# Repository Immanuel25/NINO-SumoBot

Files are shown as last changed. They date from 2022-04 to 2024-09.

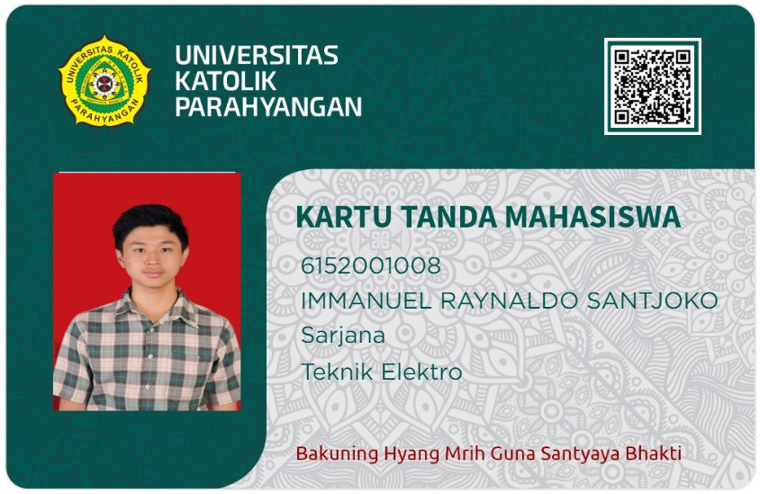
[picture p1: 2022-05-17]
NINO/ADM/KTM_Immanuel Raynaldo.jpg

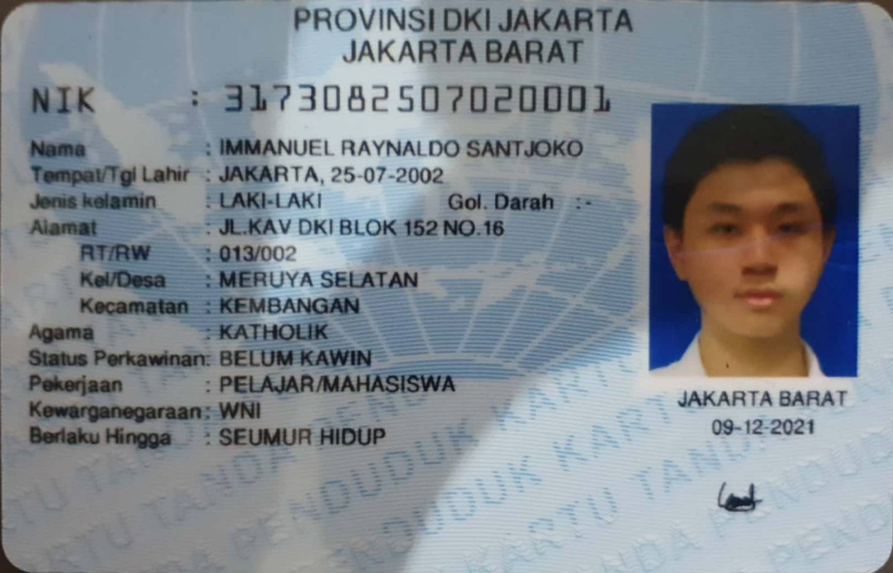
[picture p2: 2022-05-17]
NINO/ADM/KTP_Immanuel Raynaldo.jpg

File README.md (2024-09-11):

# Sumorobot Project

This repository contains the hardware and software files for a sumorobot built using an ESP32 and controlled via a PS4 controller. The robot weighs 2.5 kg and is designed for sumo robot competitions.

## Features

- **ESP32 and PS4 Controller**: The sumorobot is controlled wirelessly using the PS4 controller, offering real-time control with responsive movements.
- **2.5kg Weight**: Optimized for sumo robot competitions with a robust build and weight.
- **Custom Hardware and Software**: Includes both the hardware design and software code necessary to operate the robot.

## How to Use

1. Clone the repository.
2. Download and install PS4 to ESP32 library, check your PS4 bluetooth mac adress and update the code.
3. Upload the code to your ESP32 using Arduino IDE or PlatformIO.
4. Connect the PS4 controller wirelessly via Bluetooth.
5. Assemble the hardware components as per the documentation.

## Contributing

Feel free to fork this repository and submit pull requests with improvements or additional features.

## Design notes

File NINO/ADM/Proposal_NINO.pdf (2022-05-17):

# NINO

Niko & Noel

## LAMPIRAN

Daftar Komponen & Jadwal Kegiatan (https://docs.google.com/spreadsheets/d/1sjoTqLaU7VVk1JxIgI_WoqWyt1DAkXqaIjDHaI9r2Wg/edit?usp=sharing) GitHub (https://github.com/Immanuel25/NINO-SumoBot)

# DESAIN MEKANIK

## DESAIN NINO

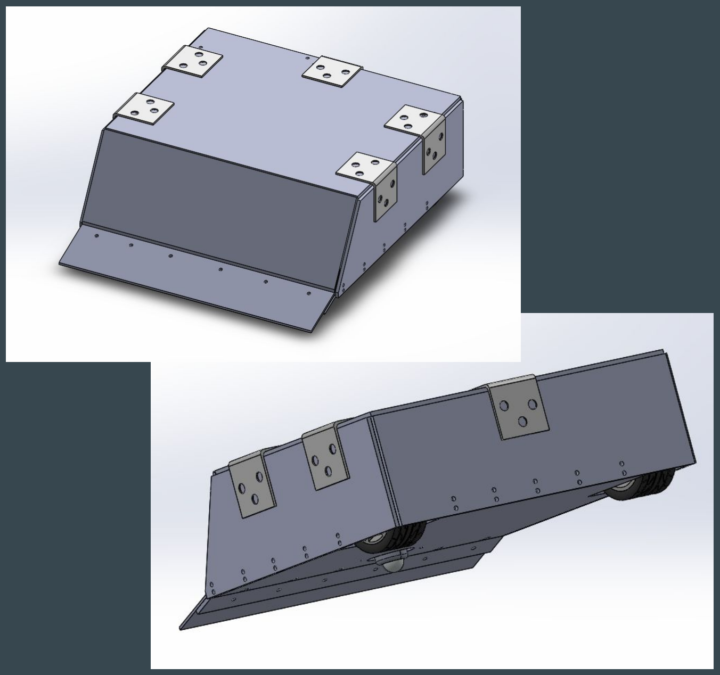
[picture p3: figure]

Bahan yang digunakan, Ketebalan :
1. Aluminium, 3mm : Untuk Plat Bawah
2. StainLess , 2mm : Untuk Ramp Bawah dan Ramp Atas
3. Akrilik, 3 mm : Untuk Penutup Atas, Kanan, Kiri , dan Belakang
Ukuran Sumo Robot :
Lebar = 24 +- cm
Panjang = 26 +- cm
Tinggi = 8,43 +- cm
Tinggi Plat Bawah ke tanah = 1 cm

## DESAIN NINO

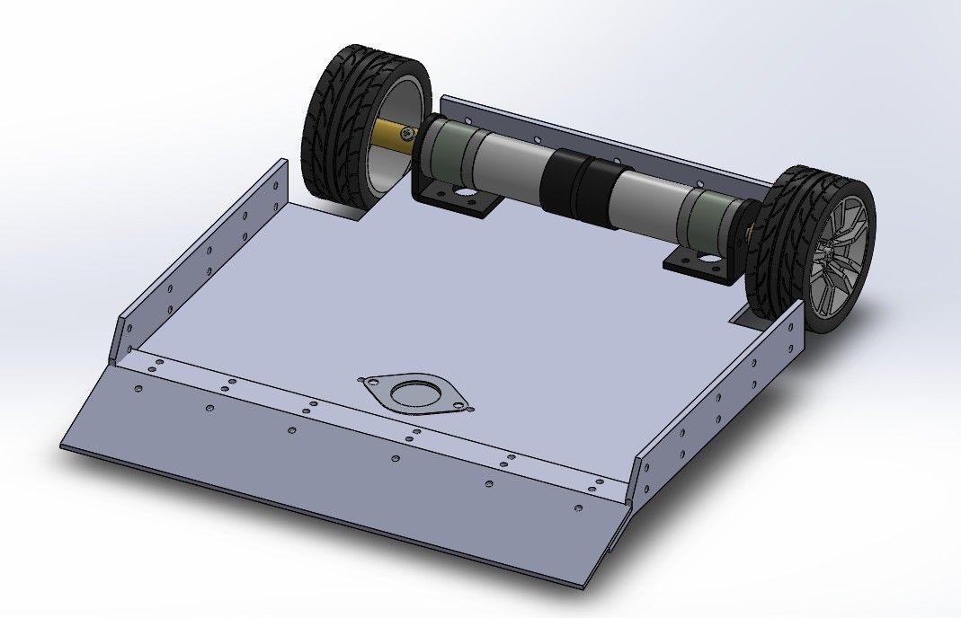
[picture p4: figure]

Bila Diberi Roda Akan tampak seperti ini

2 roda besar di belakang dan 1 caster di depan

Roda akan dicetak dengan bahan silikon menggunakan pipa paralon

Tampak Atas | Tampak Samping

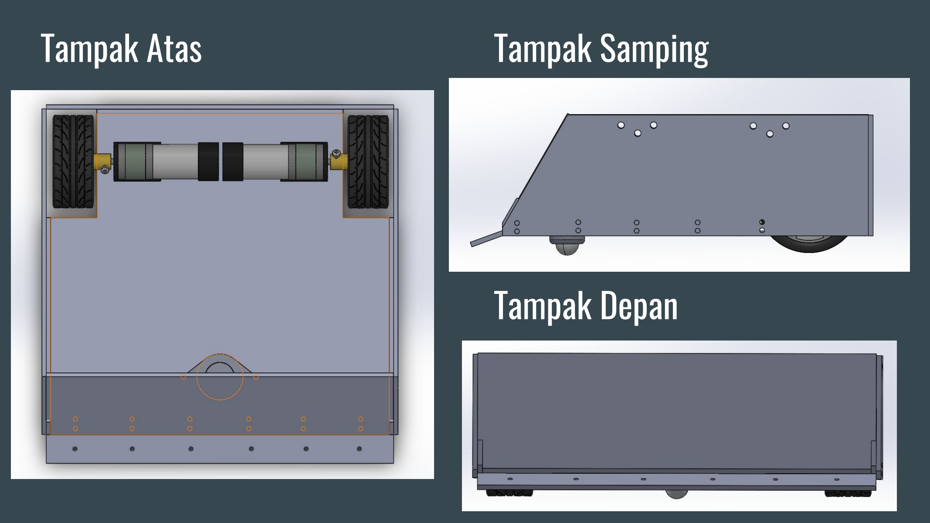
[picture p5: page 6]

## Tampak Depan

## DIMENSI DARI

ROBOT NINO | 15

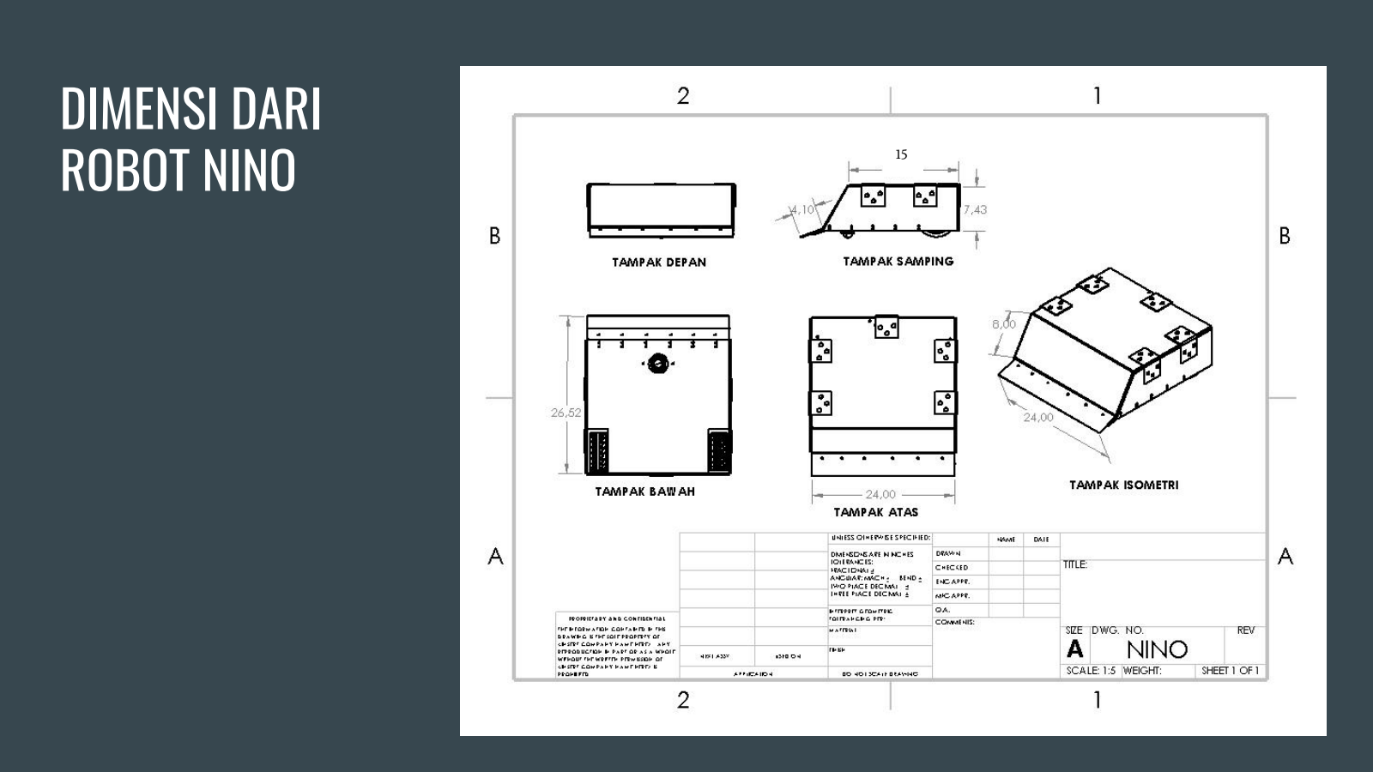
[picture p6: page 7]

## KOMPONEN MEKANIK

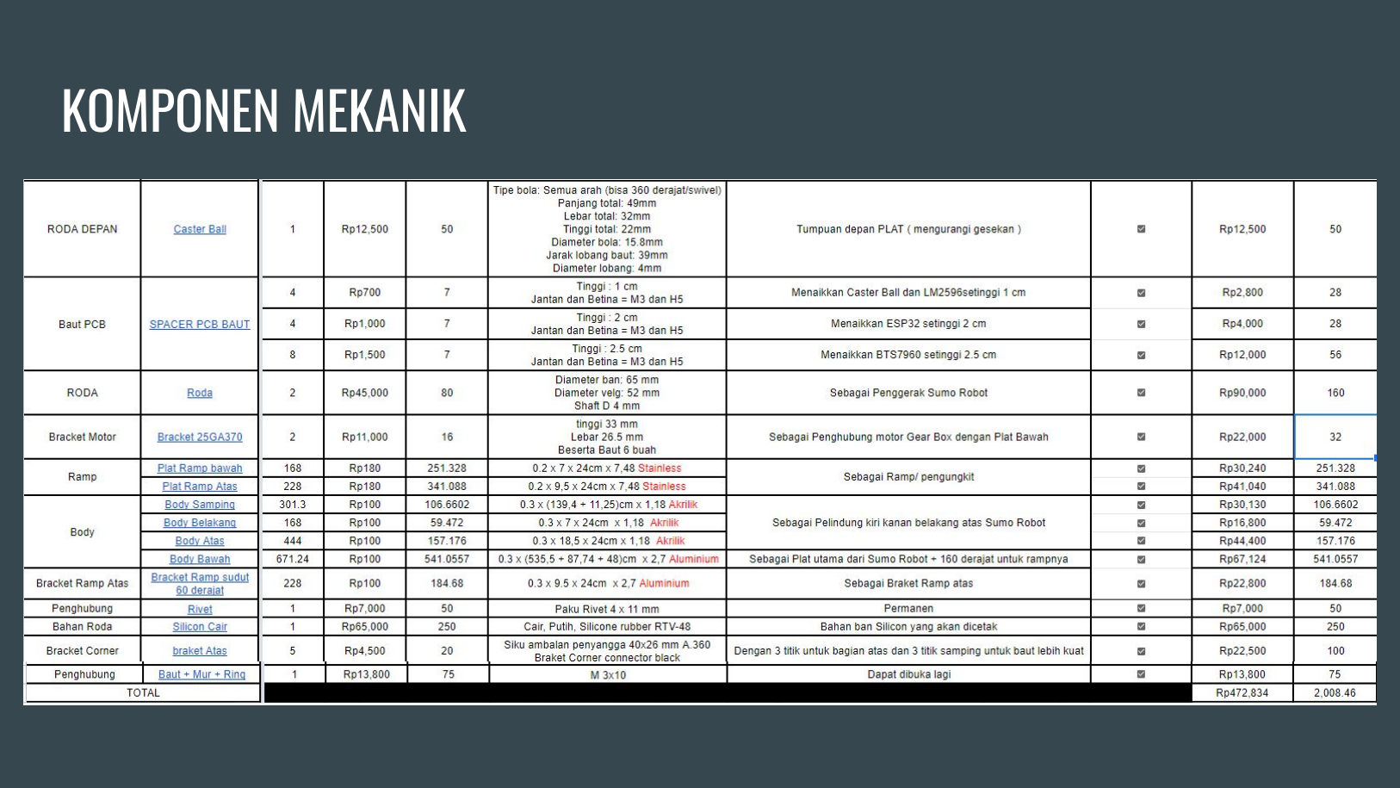
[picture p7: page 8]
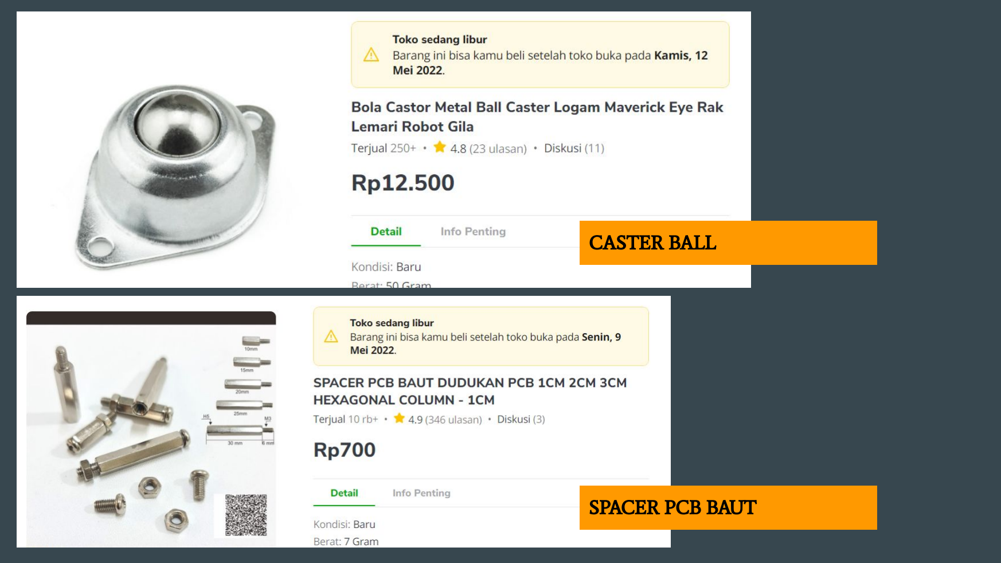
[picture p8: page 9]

CASTER BALL

SPACER PCB BAUT

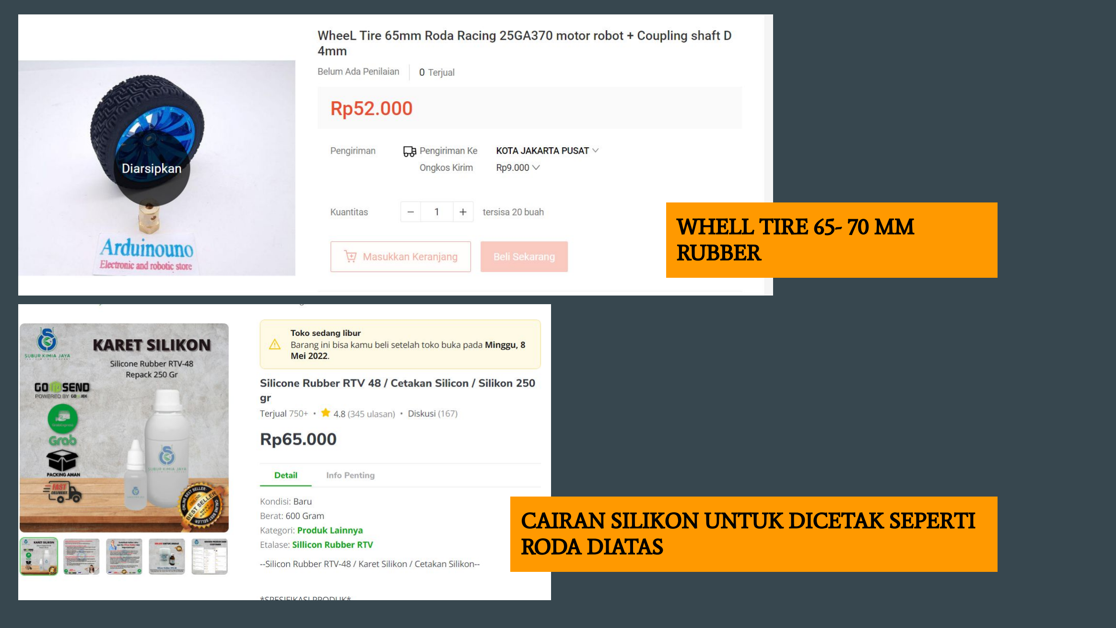
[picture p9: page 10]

WHELL TIRE 65- 70 MM
RUBBER

CAIRAN SILIKON UNTUK DICETAK SEPERTI RODA DIATAS

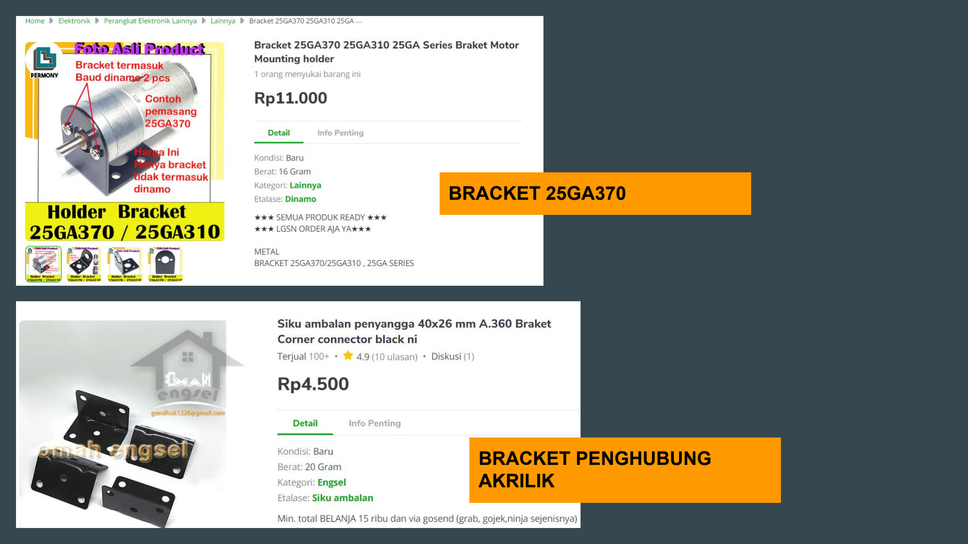
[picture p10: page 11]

BRACKET 25GA370

BRACKET PENGHUBUNG
AKRILIK

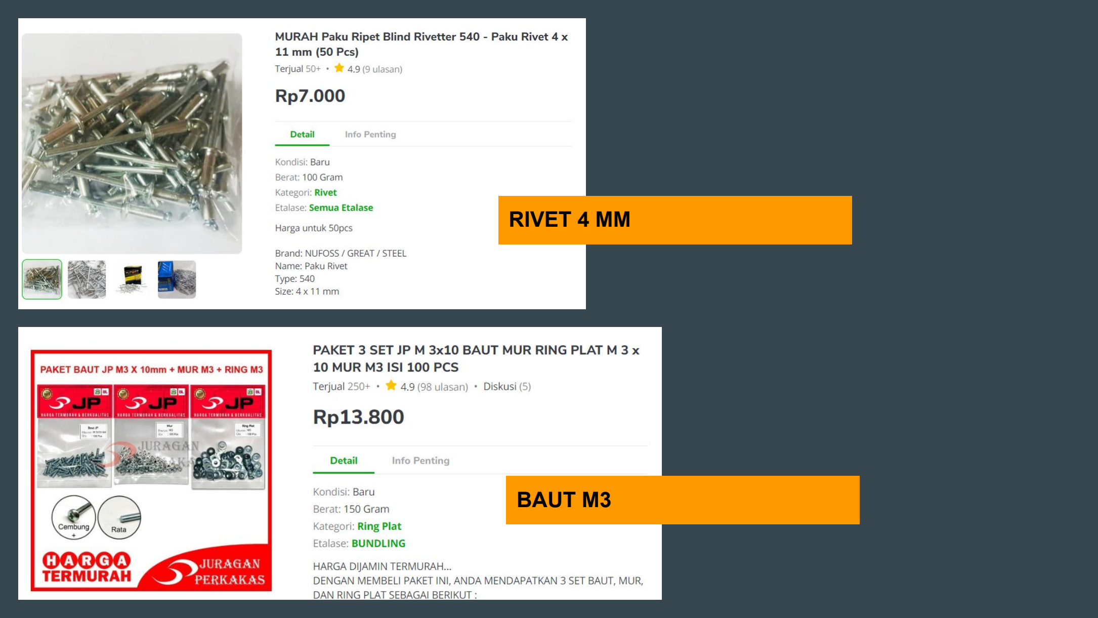
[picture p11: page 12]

RIVET 4 MM

BAUT M3

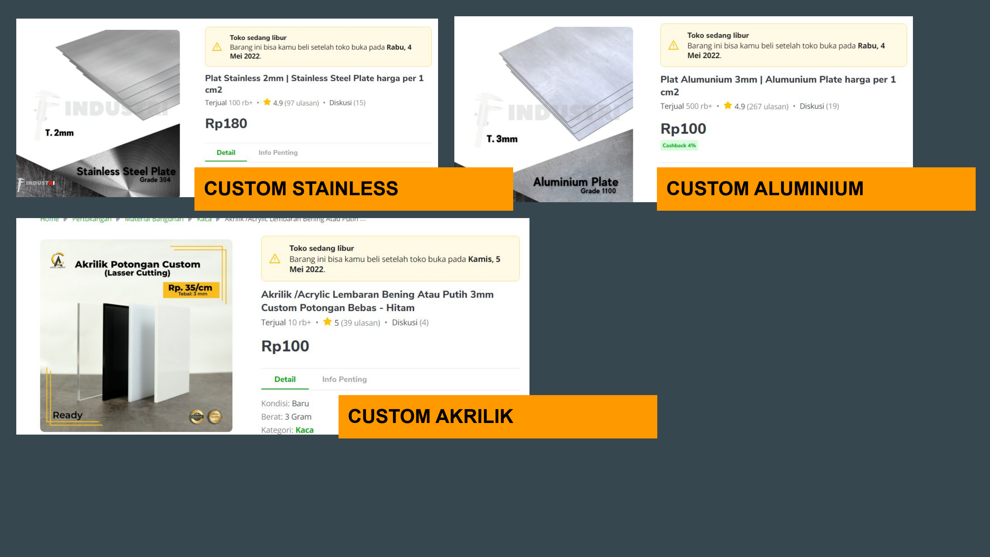
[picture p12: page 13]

CUSTOM AKRILIK

CUSTOM STAINLESS | CUSTOM ALUMINIUM

# KOMPONEN ELEKTRONIK

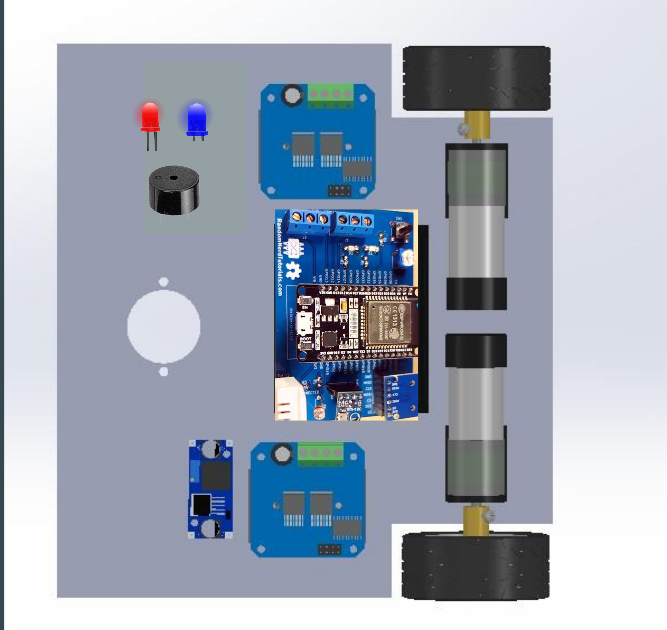
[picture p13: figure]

## RANGKAIAN ELEKTRONIK

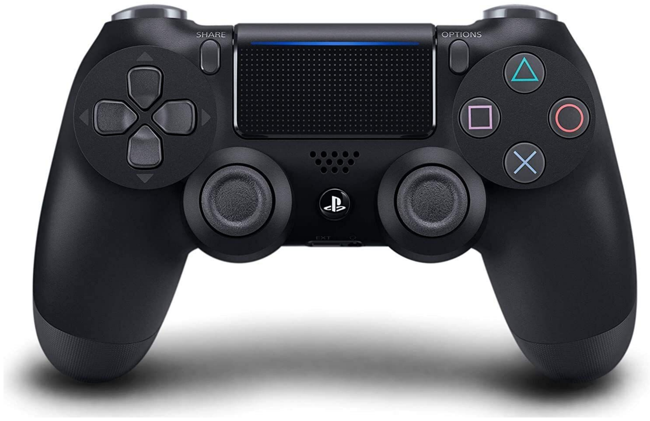
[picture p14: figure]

# KONTROLER

Sudah ada dan sudah terbiasa (karena sering main ps),
menggunakan bluetooth (ada librarynya)

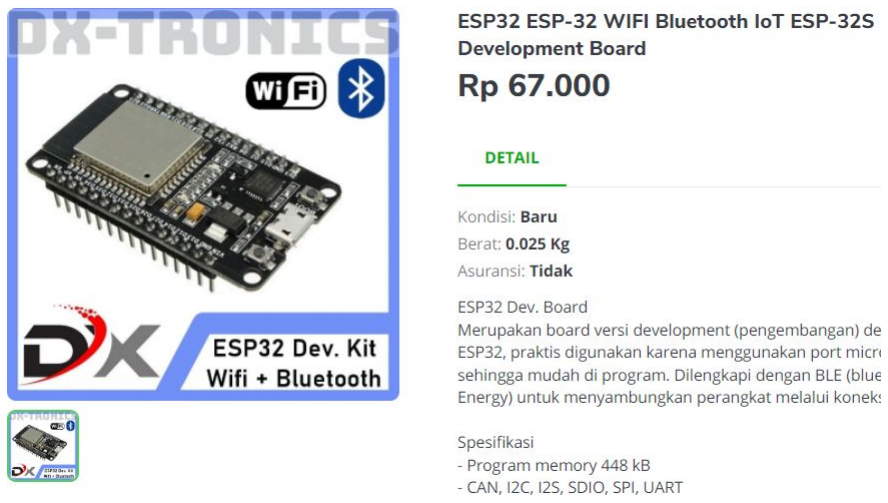
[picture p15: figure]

# MICRO CONTROLLER

Clock speednya lebih cepat 7.5x lipat dari arduino nano
integrated BLE V4.2

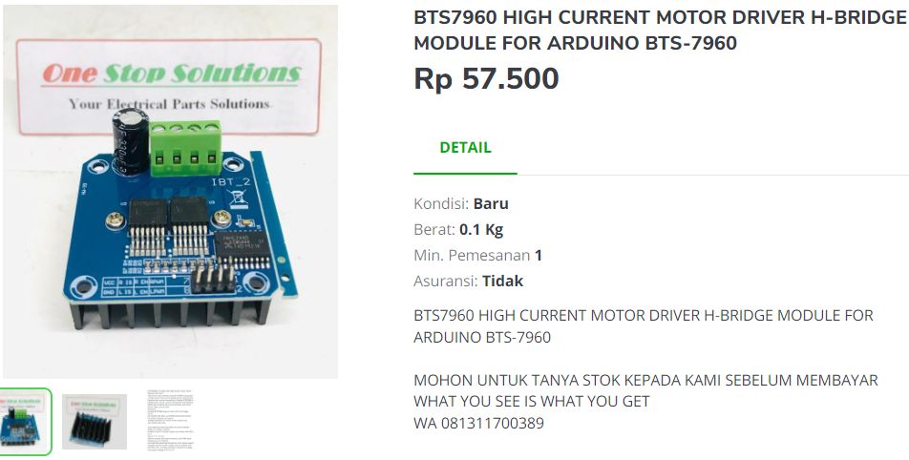
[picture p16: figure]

# MOTOR DRIVER

Menggunakan mosfet, arus max 43A, sudah ada heatsink, murah, ada pengukur arus (integrated)

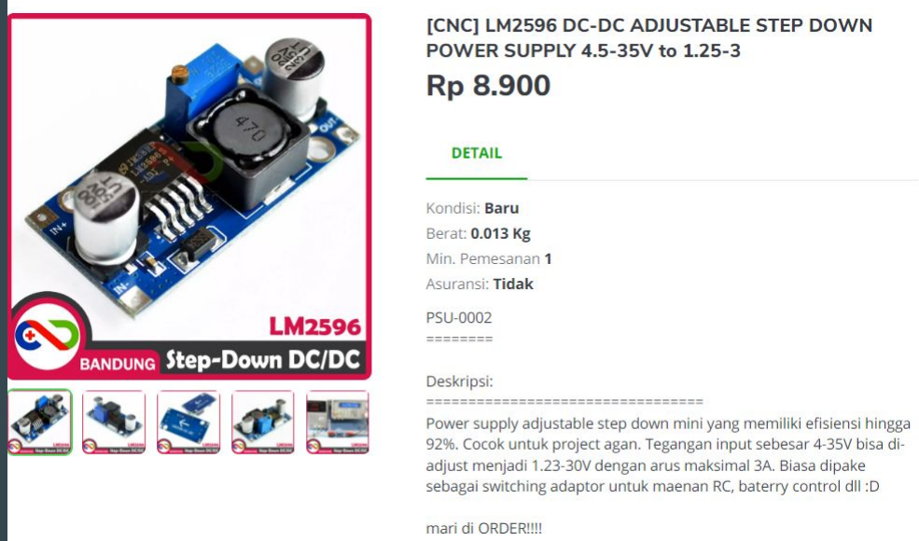
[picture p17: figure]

# STEP DOWN

## (PSU ESP32)

Bisa nurunin ke 6v, efisien, ringan

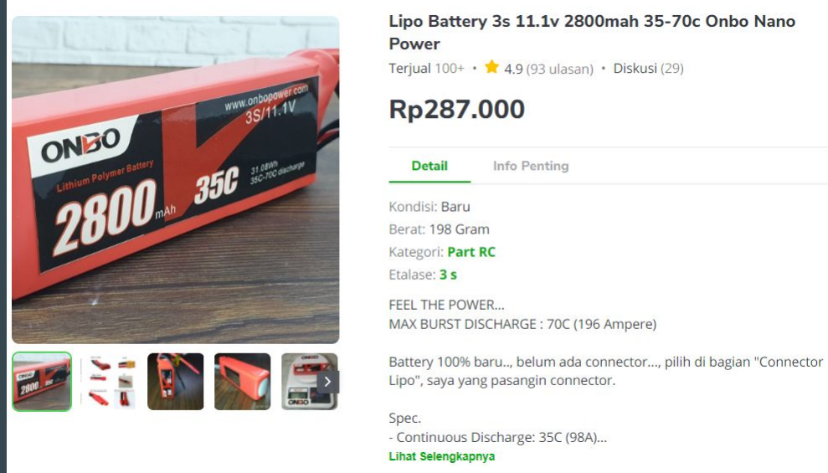
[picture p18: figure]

# Baterai

3S, artinya maks 12.6V, 2800 mah, Dalam pemakaian arus motor rata” (1A), robot dapat bertahan selama 1 jam 24 menit

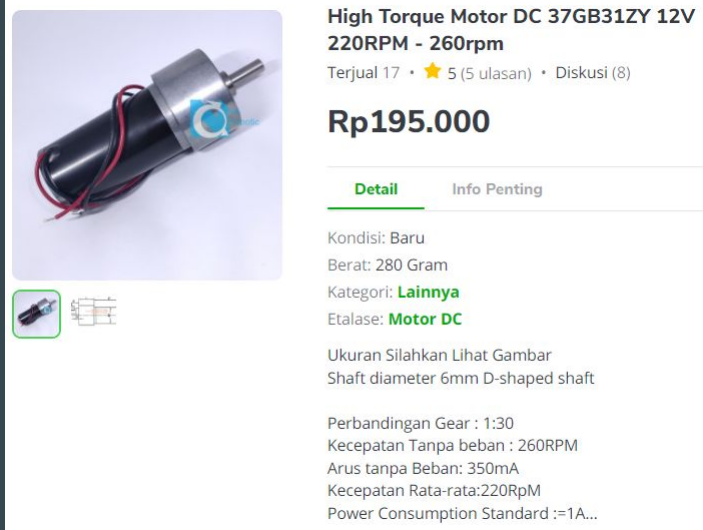
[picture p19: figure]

# MOTOR

Torsi sangat besat, arus yang digunakan juga banyak

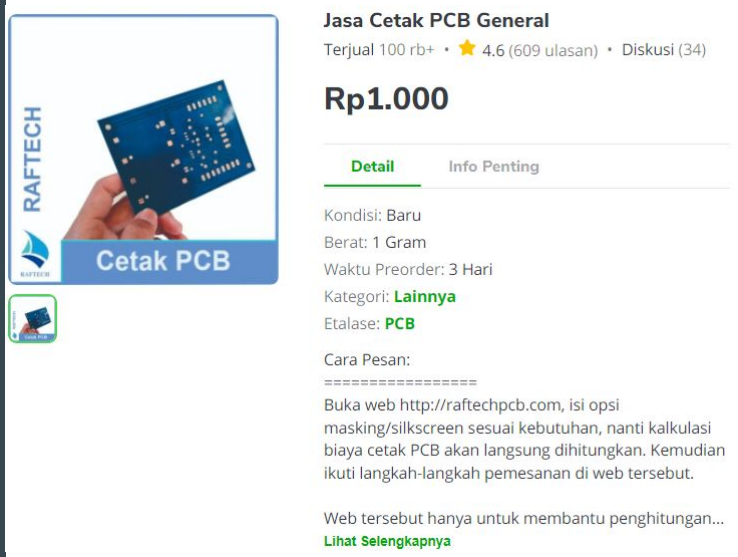
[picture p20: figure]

# CUSTOM PCB #1

Lebih tahan banting, praktis, debugging tinggal liat layar (semoga tidak salah)
- Nunggu sekitar 3+2 hari

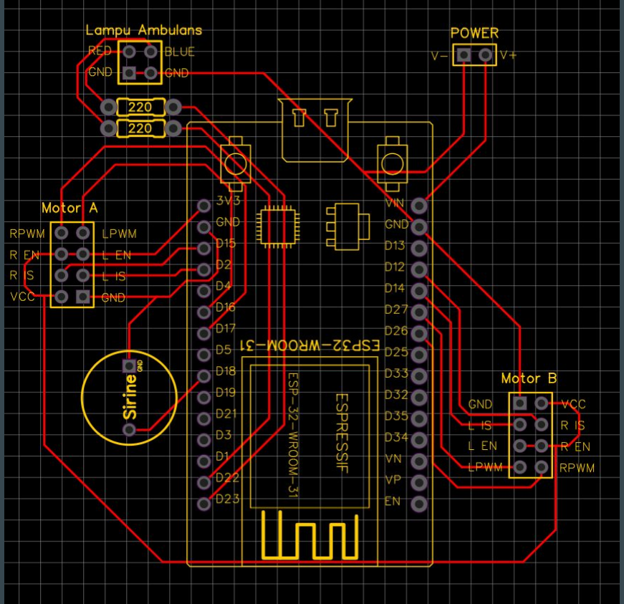
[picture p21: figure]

## RANGKAIAN PCB

## Komponen Listrik

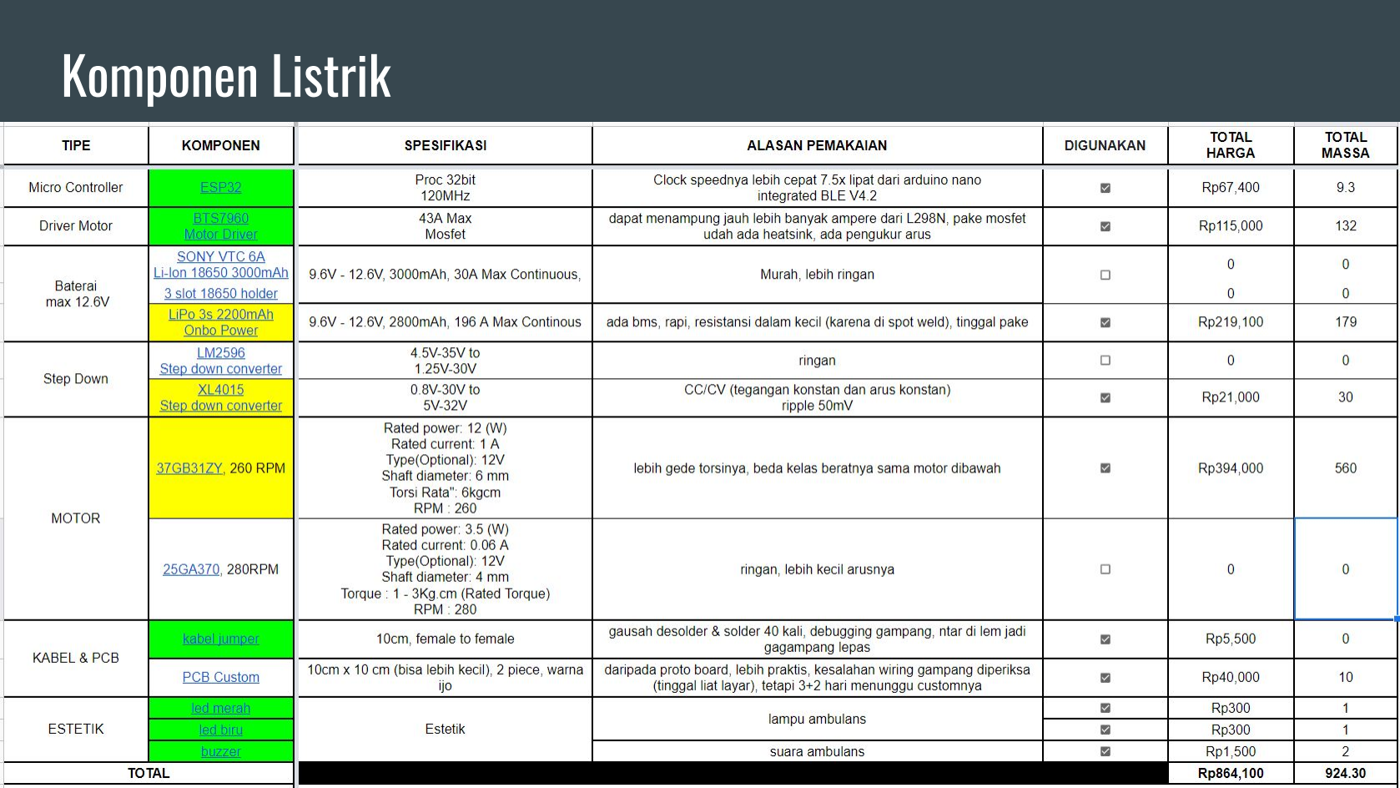
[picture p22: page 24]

# CARA KERJA KENDALI

# KENDALI NORMAL

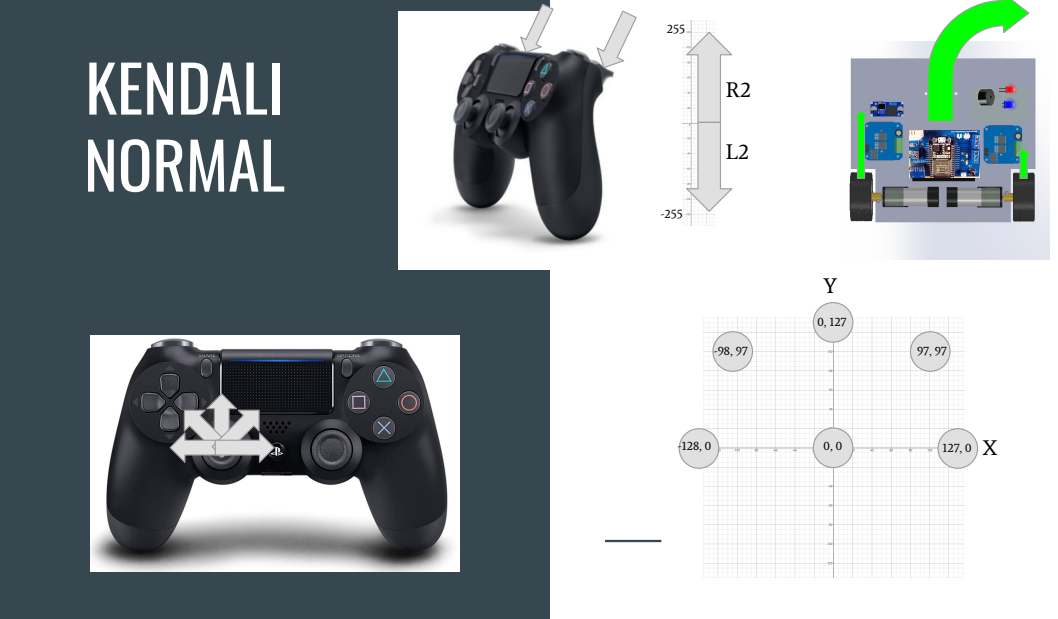
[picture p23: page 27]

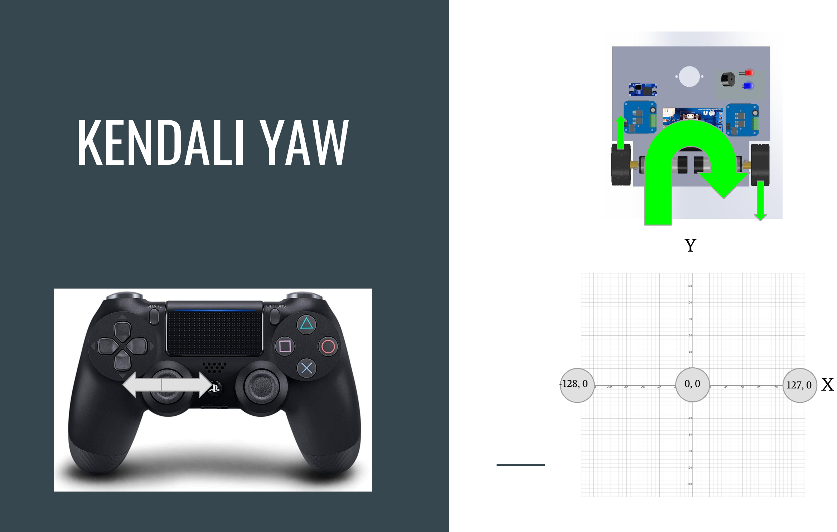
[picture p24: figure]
KENDALI YAW

# H-Bridge

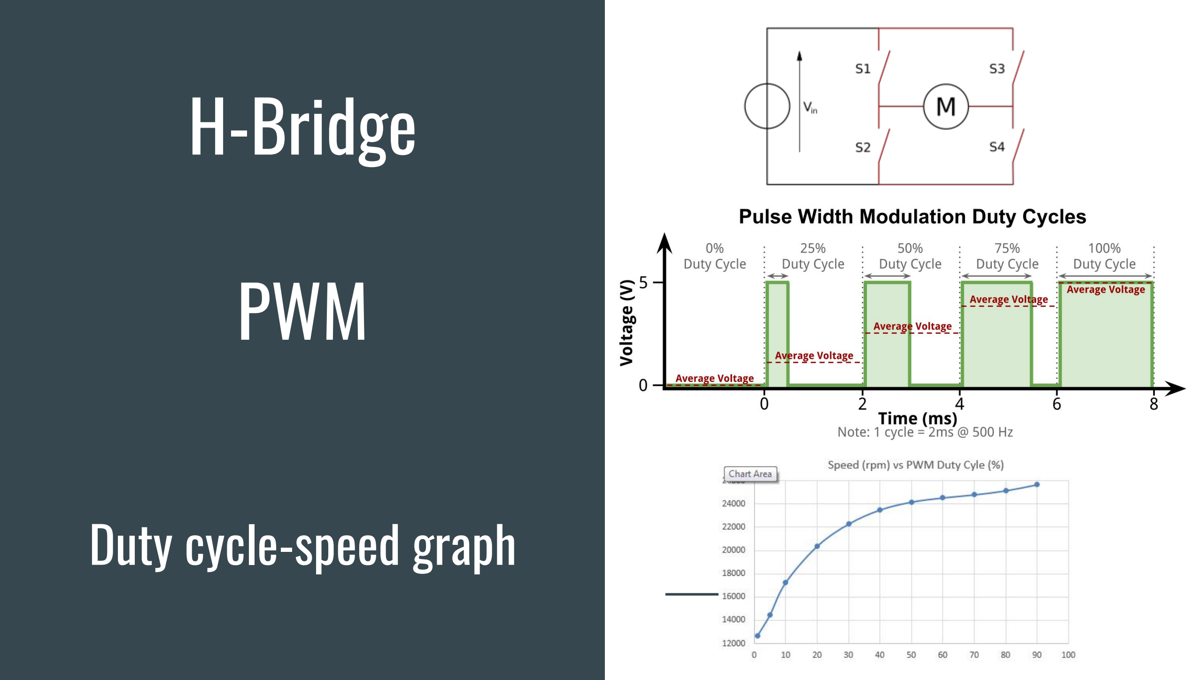
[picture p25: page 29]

# PWM

# Duty cycle-speed graph

# CARA MENANG

TRAKSI BAN
Center of gravity
Sistem penggerak
Jenis ban
Berat benda
TORSI RODA
Watt Motor
Rasio gear
PENGENDALI
Latihan
Code efektif
Kalibrasi

# STRATEGI

TIPE PENYERANG
Selalu menghadap robot lawan Menang karena lebih kuat
mendorong

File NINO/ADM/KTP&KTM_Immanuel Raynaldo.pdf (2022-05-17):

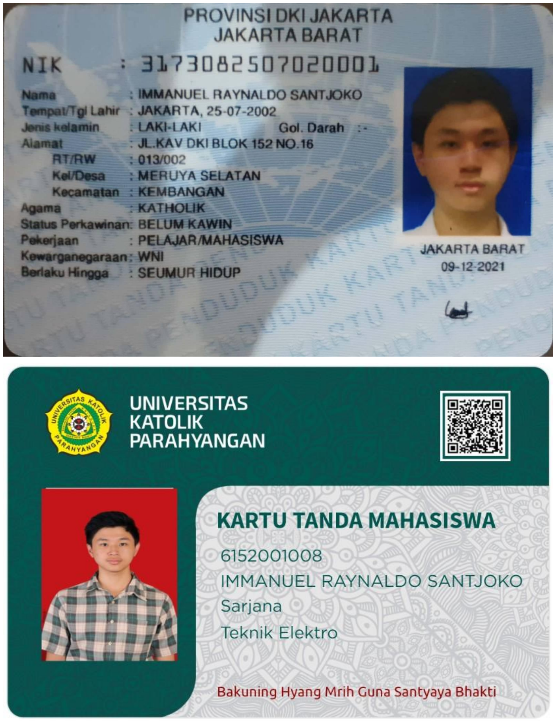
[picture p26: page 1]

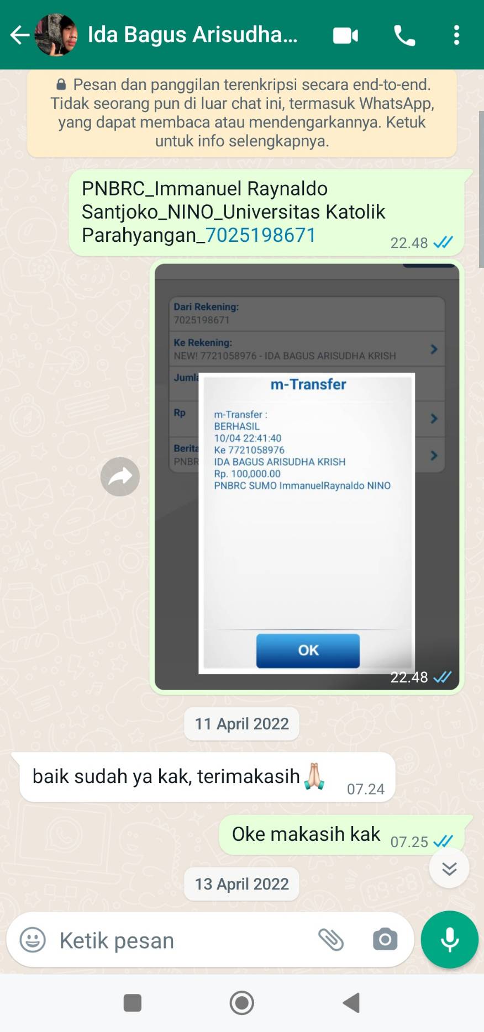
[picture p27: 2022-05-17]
NINO/ADM/BuktiPeserta_NINO.jpg

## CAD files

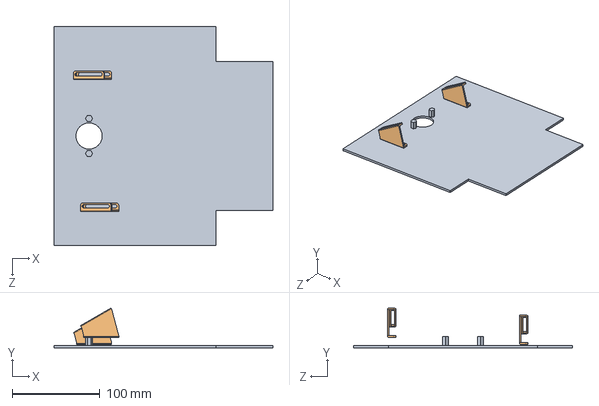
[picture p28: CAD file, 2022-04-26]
Assem1.SLDASM
250.0 x 45.4 x 250.0 mm
desain noel
bracketramp x 2

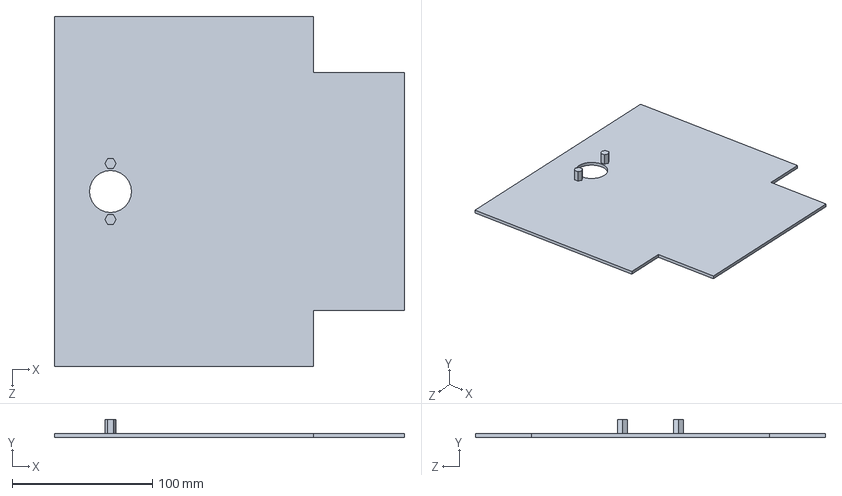
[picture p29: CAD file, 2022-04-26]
desain noel.SLDPRT
250.0 x 13.0 x 250.0 mm

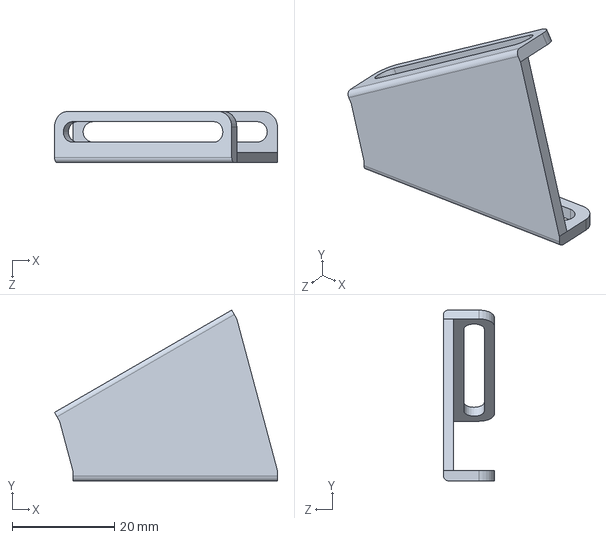
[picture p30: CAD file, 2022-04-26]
bracketramp.SLDPRT
43.6 x 33.4 x 10.0 mm

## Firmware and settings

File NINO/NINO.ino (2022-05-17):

#include <PS4Controller.h>

// FITUR YANG KURANG
// 1. Sirine dan lampu ambulans
// 2. Baca arus dari bts7960
// 3. COMBO MOVE (LMAO)

int MAXSPEEDA = 800; // 800/1023 x100% duty cycle 
int MAXSPEEDB = 800; // 800/1023 x100% duty cycle
int INITIALSPEED = 64; 

int speedA = 0;
int speedB = 0;
int throttle = 0;

const int freq = 5000;
const int resolution = 10; //Resolution 8, 10, 12, 15

bool xButtonState = false;
bool alarmState = false;
int waktuNi = 0;
int ganjilGenap = 0;


#define pinMerah 33 // GPIO23 (D23)
#define pinBiru 32 // GPIO22 (D23)
#define pinBuzzer 18 // GPIO18 (D18)

// pins for motor A
#define RPWM_CHA 0 // CHANNEL PWM FORWARD MOTOR A
#define RPWM_A 17 // GPIO17 (D17)
//#define R_IS_A 15 // GPIO15 (D15)

#define LPWM_CHA 1 // CHANNEL PWM REVERSE MOTOR A
#define LPWM_A 16 // GPIO16 (D16)
//#define L_IS_A 2 // GPIO2 (D2)
// motor A pins end here

// pins for motor B
#define RPWM_CHB 2 // CHANNEL PWM FORWARD MOTOR B
#define RPWM_B 26 // GPIO26 (D26)
//#define R_IS_B 12 // GPIO12 (D12)

#define LPWM_CHB 3 // CHANNEL PWM REVERSE MOTOR B
#define LPWM_B 27 // GPIO27 (D27)
//#define L_IS_B 14 // GPIO14 (D14)
// motor B pins end here

#define CW 1 //
#define CCW 0 //
#define debug 1 //


void setup() { 
  Serial.begin(115200);
  PS4.begin("40:99:22:d3:2e:ac");
  Serial.println("Ready.");

  // Buat PWM
  ledcSetup(RPWM_CHA, freq, resolution);
  ledcAttachPin(RPWM_A, RPWM_CHA);
  
  ledcSetup(LPWM_CHA, freq, resolution);
  ledcAttachPin(LPWM_A, LPWM_CHA);
  
  ledcSetup(RPWM_CHB, freq, resolution);
  ledcAttachPin(RPWM_B, RPWM_CHB);
  
  ledcSetup(LPWM_CHB, freq, resolution);
  ledcAttachPin(LPWM_B, LPWM_CHB);

//  pinMode(R_IS_A, INPUT); // ngasih tau berapa arus ngalir
//  pinMode(L_IS_A, INPUT); 
//  pinMode(R_IS_B, INPUT);  
//  pinMode(L_IS_B, INPUT);  

  pinMode(pinMerah, OUTPUT);
  pinMode(pinBiru, OUTPUT);
  pinMode(pinBuzzer, OUTPUT);

  ledcAttachPin(pinBuzzer, 4);
}

void loop() {
  if (PS4.isConnected()) {
    throttle = PS4.R2Value()-PS4.L2Value(); 
    
    if (throttle<49 and throttle>-50) { //buat ngarahin robot + yaw
      speedA = map(PS4.LStickX(), 0, 127, 0, MAXSPEEDA*1);
      speedB = map(-PS4.LStickX(), 0, 127, 0, MAXSPEEDB*1);
    }
    
    else { //buat mode setir biasa
      speedA = map(INITIALSPEED+PS4.LStickY()+PS4.LStickX()/2, 0, 200, 0, throttle);
      speedB = map(INITIALSPEED+PS4.LStickY()-PS4.LStickX()/2, 0, 200, 0, throttle);
  
      speedA = map(speedA, 0, 255, 0, MAXSPEEDA);
      speedB = map(speedB, 0, 255, 0, MAXSPEEDB);
  
      }
    
    if (speedA>20){ // motor A CW
      ledcWrite(LPWM_CHA, 0);
      ledcWrite(RPWM_CHA, speedA);
    }
    else if (speedA<-20){ // motor A CCW
      ledcWrite(RPWM_CHA, 0);
      ledcWrite(LPWM_CHA, -speedA);
    }
    else{ // motor A berenti
      ledcWrite(RPWM_CHA, 0);
      ledcWrite(LPWM_CHA, 0);
    }
    
    if (speedB>20){ // motor B CCW
      ledcWrite(RPWM_CHB, 0);
      ledcWrite(LPWM_CHB, speedB);
    }
    else if (speedB<-20){ // motor B CW
      ledcWrite(LPWM_CHB, 0);
      ledcWrite(RPWM_CHB, -speedB);
    }
    else{ // motor B berenti
      ledcWrite(RPWM_CHB, 0);
      ledcWrite(LPWM_CHB, 0);
    }
    
    if (debug==1){
      Serial.print("speedA: ");
      Serial.print(speedA);
      Serial.print(" speedB: ");
      Serial.println(speedB);
      Serial.println("");
      delay(100);
    }
 
    if (PS4.Cross() and xButtonState == false) {
      if (alarmState == true){ //matiin alarm
        digitalWrite(pinMerah, LOW);
        digitalWrite(pinBiru, LOW);
        ledcWrite(4, 0);
        alarmState = false;
      }
      else {
        alarmState = true;
        waktuNi = millis();
      }
    }
    
    xButtonState = PS4.Cross();
  
    if (alarmState == true){
      ganjilGenap = (millis() - waktuNi)/500;
      ganjilGenap = ganjilGenap%2;
      
      if (ganjilGenap == 0){
        digitalWrite(pinMerah, LOW);
        digitalWrite(pinBiru, HIGH);
        ledcWriteTone(4, 50);
      }
      else{
        digitalWrite(pinMerah, HIGH);
        digitalWrite(pinBiru, LOW);
        ledcWriteTone(4, 500);
      }
    }
  }
  else{
    Serial.println("disconnected");
    delay(100);
  }
}





  

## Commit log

2022-04-26 jadi rusak
    [Assem1.SLDASM, bracketramp.SLDPRT, desain noel.SLDPRT]
2022-04-27 Buat kalo udah pake pcb
